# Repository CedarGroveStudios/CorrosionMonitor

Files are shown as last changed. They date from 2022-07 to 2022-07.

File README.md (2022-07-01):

# Corrosion_Monitor
 A CircuitPython and IoT version of the classic Workshop Corrosion Detector

Uses __CedarGroveStudios/Unit_Converter__ custom CircuitPython library.

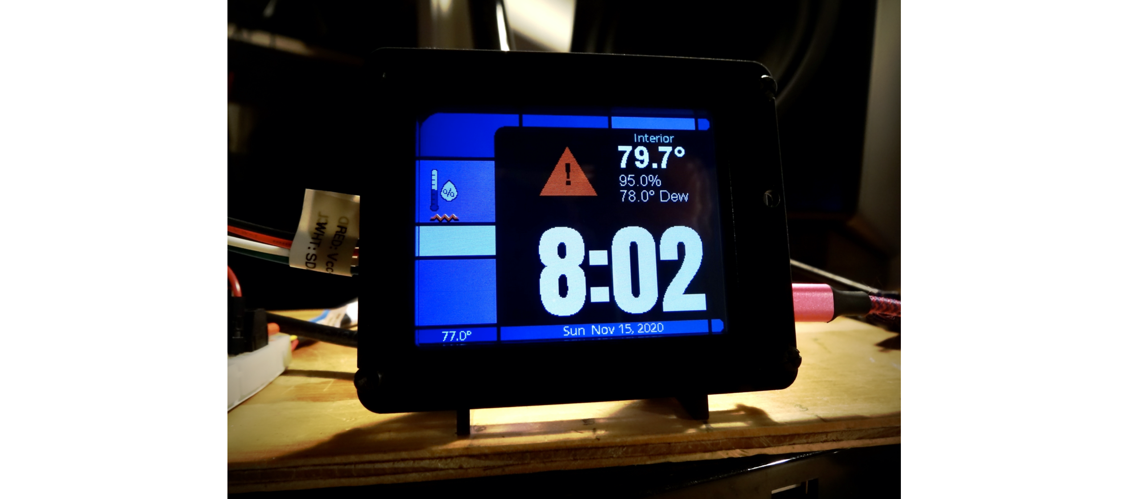
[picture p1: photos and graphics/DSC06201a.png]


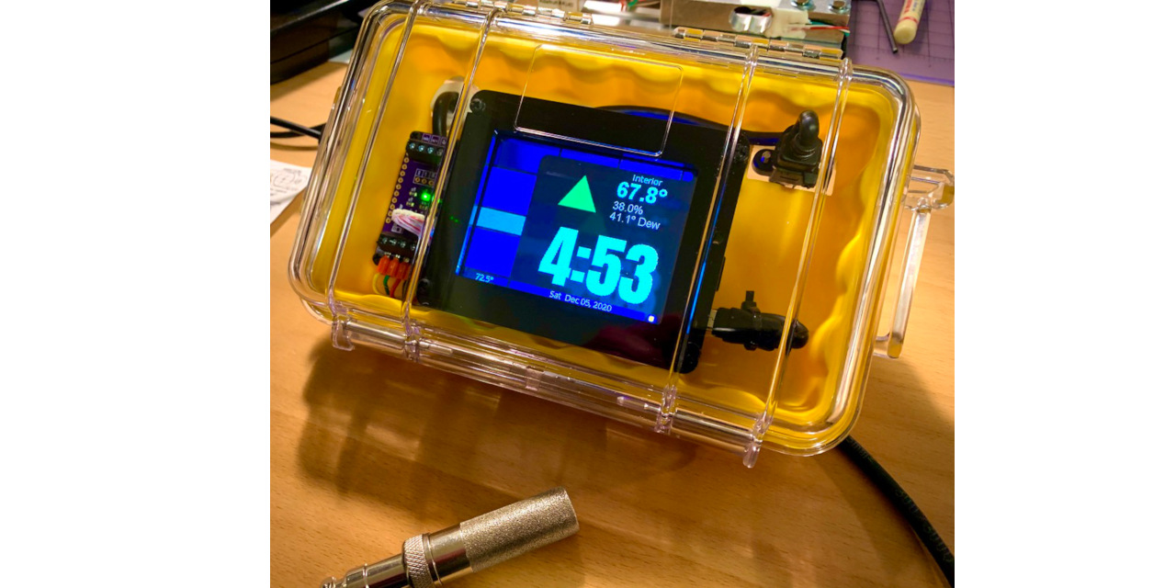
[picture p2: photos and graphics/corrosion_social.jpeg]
Corrosion_Monitor


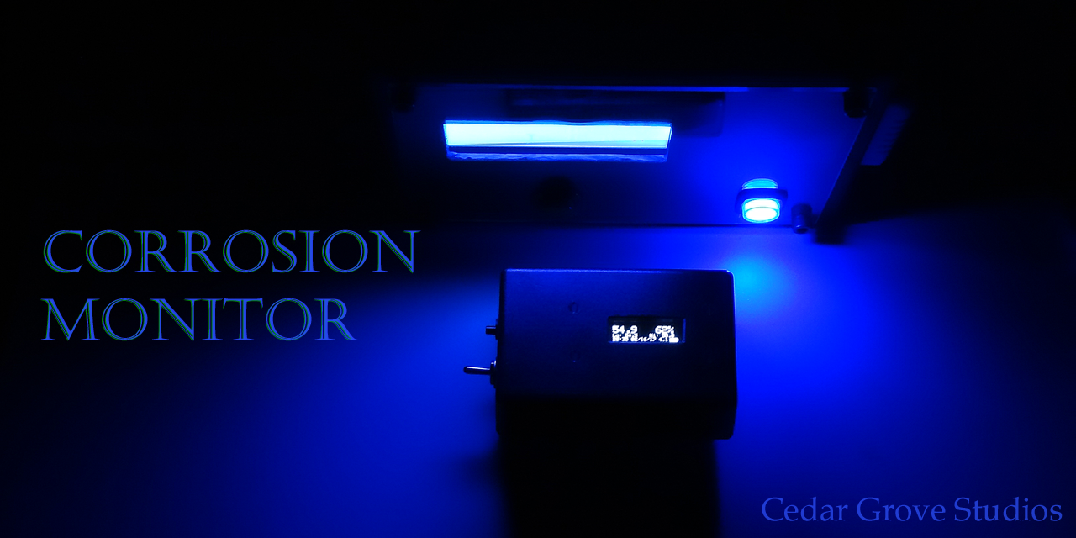
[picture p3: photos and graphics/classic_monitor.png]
Classic_Monitor


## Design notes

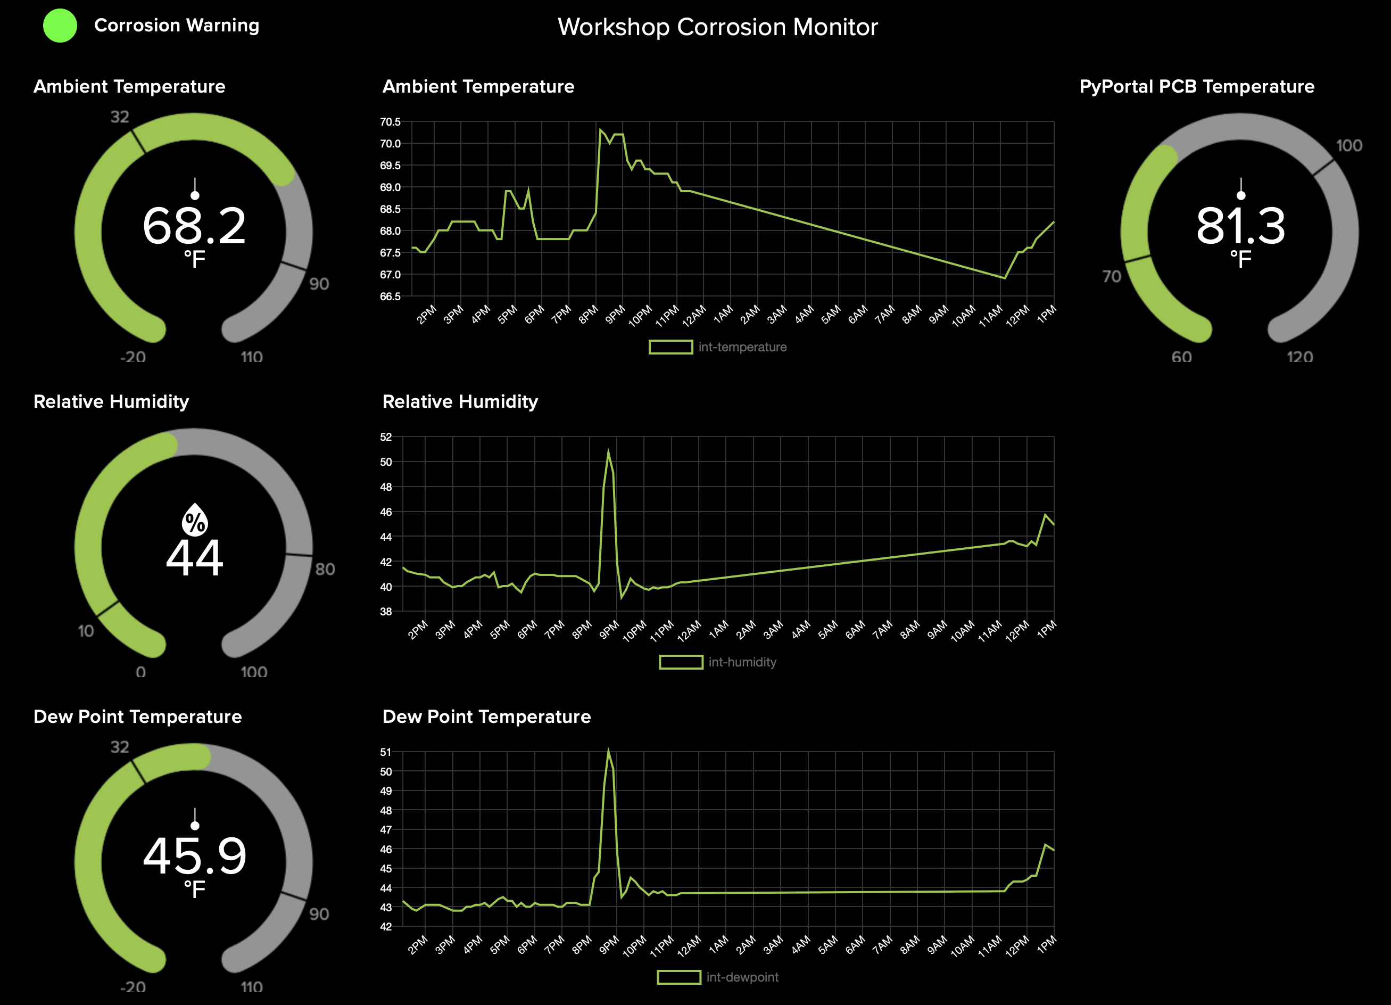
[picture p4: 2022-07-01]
photos and graphics/Screen Shot 2020-11-15 at 1.06.47 PM.png

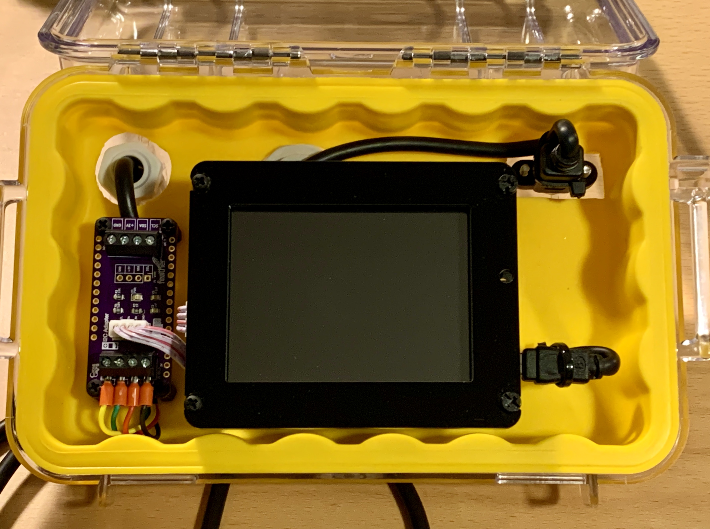
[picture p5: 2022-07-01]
photos and graphics/0E669820-88BB-440B-91F6-CADB1FE80EF4_1_201_a.jpeg

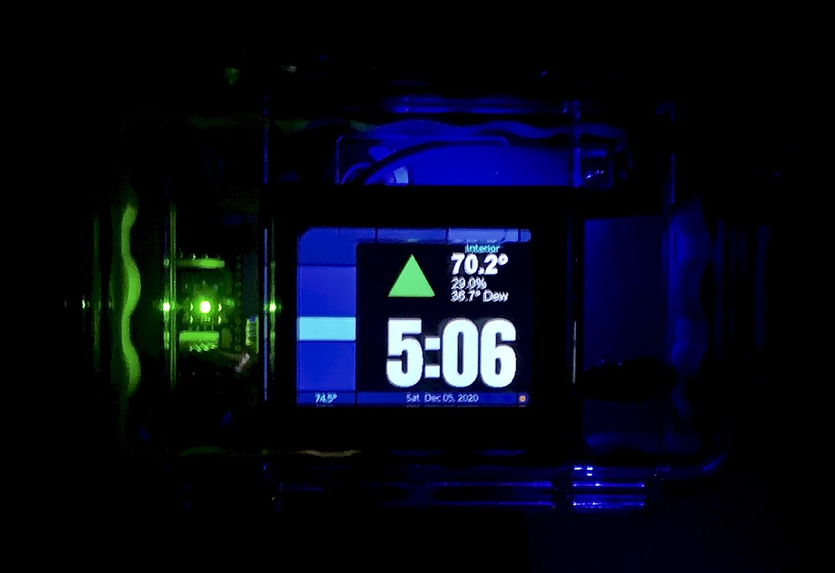
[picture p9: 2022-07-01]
photos and graphics/D59A51D9-286E-4AAB-B2BA-2F82D71A623C_1_105_c.jpeg

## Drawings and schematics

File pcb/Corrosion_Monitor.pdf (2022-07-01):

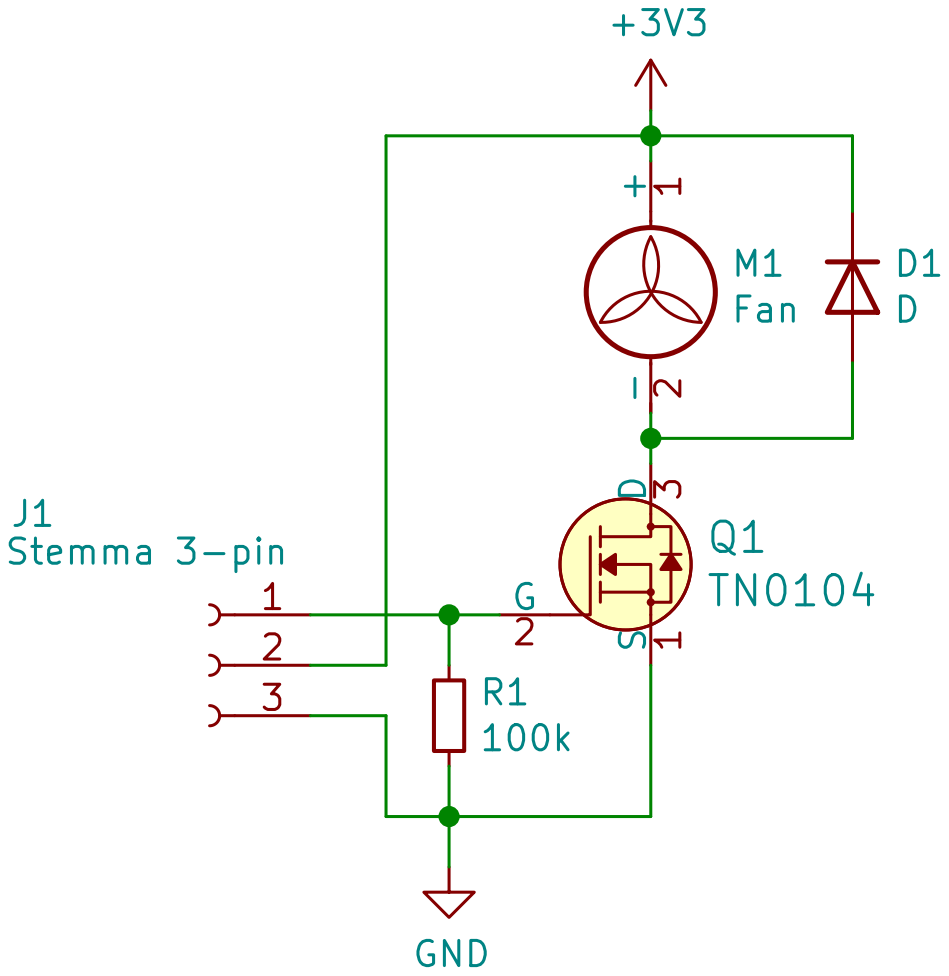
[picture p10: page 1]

File: Corrosion_Monitor.sch Sheet: / Cedar Grove Studios

Id: 1/1 Title: Corrosion_Monitorf Fan Controller

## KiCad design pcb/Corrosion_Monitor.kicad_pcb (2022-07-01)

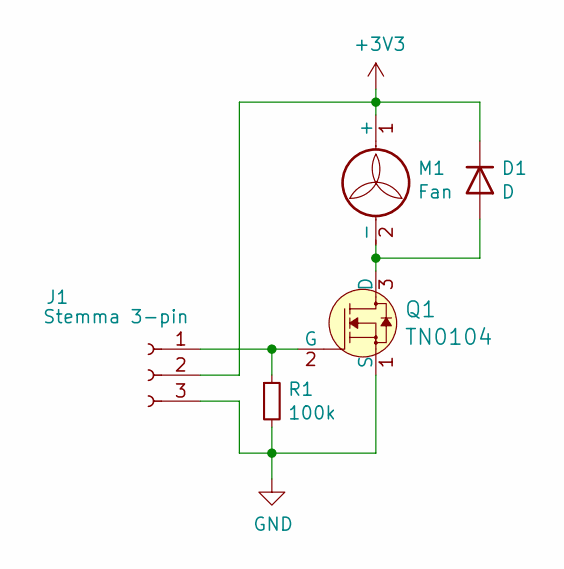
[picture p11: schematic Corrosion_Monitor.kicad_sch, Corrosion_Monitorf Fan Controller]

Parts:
D1: D; D_T-1_P2.54mm_Vertical_KathodeUp
J1: Stemma 3-pin; PinHeader_1x03_P2.54mm_Vertical
M1: Fan; PinHeader_1x02_P2.54mm_Vertical
Q1: TN0104; TO-92S; MPN 2N7000; Digi-Key_PN 2N7000FS-ND
R1: 100k; R_Axial_DIN0204_L3.6mm_D1.6mm_P2.54mm_Vertical

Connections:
+3V3: D1.1 (K), J1.2, M1.1 (+)
GND: J1.3, Q1.1 (S), R1.2
unnamed: D1.2 (A), M1.2 (-), Q1.3 (D)
unnamed: J1.1, Q1.2 (G), R1.1

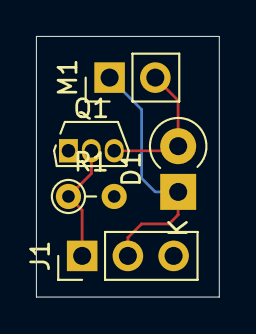
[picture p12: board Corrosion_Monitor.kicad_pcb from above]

Board: 2 copper layers, 10.2 x 14.5 mm, 5 parts (0 on the bottom side), 4 nets.

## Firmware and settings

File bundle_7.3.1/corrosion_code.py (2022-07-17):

# Workshop Corrosion Monitor
# Copyright 2018 to 2022 by JG for Cedar Grove Maker Studios
#
# corrosion_code.py 2022-07-17 v4.0717

import time
import board
import supervisor
from digitalio import DigitalInOut, Direction
from simpleio import map_range
from corrosion_display import CorrosionDisplay
from corrosion_sensors import CorrosionTempHumid, CorrosionTemp
from cedargrove_shadow_detector import ShadowDetector

print("running corrosion_code.py")

# Reduce status neopixel brightness to help keep things cool on error exit
# TODO: reduce TFT backlight brightness upon exit
supervisor.set_rgb_status_brightness(16)

# Force a restart upon error exit to keep things alive when the eventual
#   internet error happens
supervisor.set_next_code_file(filename="code.py", reload_on_error=True)

# fmt: off
# Adafruit IO Feed Names
SHOP_TEMP     = "shop.int-temperature"      # workshop temperature   (F)
SHOP_HUMID    = "shop.int-humidity"         # workshop humidity      (%)
SHOP_DP       = "shop.int-dewpoint"         # workshop dew point     (F)
SHOP_CORR     = "shop.int-corrosion-index"  # workshop corrosion indicator (0, 1, 2)
SHOP_PCB_TEMP = "shop.int-pcb-temperature"  # workshop device PCB temperature (F)

# Sensor and cluster sending delays
AIO_CLUSTER_DELAY  = 10  # minutes
AIO_CLUSTER_OFFSET =  5  # minutes
AIO_SENSOR_DELAY   =  2  # seconds
DUAL_SENSOR_DELAY  =  3  # seconds

# Cooling fan controls
FAN_ON_DISP_BRIGHTNESS =  0  # Display brightness when fan is running
FAN_ON_TRESHOLD_F      = 80  # Degrees Farenheit

# Gesture controls
GESTURE_DURATION = 10            # Backlight "on" duration after gesture (seconds)
GESTURE_DETECT_THRESHOLD = 0.90  # Detection threshold compared to ambient light

# Instantiate Corrosion Monitor classes
sensor  = CorrosionTempHumid(sensor="SHT31D")
pcb     = CorrosionTemp()
disp    = CorrosionDisplay(brightness=0.75)
gesture = ShadowDetector(pin=board.LIGHT, threshold=GESTURE_DETECT_THRESHOLD)

fan           = DigitalInOut(board.D4)  # D4 Stemma 3-pin connector
fan.direction = Direction.OUTPUT
fan.value     = False  # Initialize with fan off
# fmt: on

if disp.sd_card:
    print("SD card present")
else:
    print("NO SD card")

# fmt: off
while_loop_startup_init   = True   # Forces first pass through loop sections
previous_sensor_heater_on = False  # The historical sensor heater state
backlight_timer           = None   # Used for timing the backlight
backlight_on              = False  # The backlight state
clock_tick                = False  # The clock tick indicator state

aio_feed_write = True  # Enable feeds to AIO
sd_card_write  = True  # Enable sd card logging
# fmt: on

while True:
    now = time.localtime()
    format_str = "%04d-%02d-%02d, %02d:%02d:%02d"
    time_str = format_str % (now[0], now[1], now[2], now[3], now[4], now[5])

    disp.clock_tick = not disp.clock_tick  # Change the on-screen tick indicator

    if not backlight_on:
        # Check for gesture
        if gesture.detect():
            print(f"GESTURE DETECTED {time_str:16s}")
            backlight_timer = time.monotonic()
            backlight_on = True

    if backlight_on:
        # Set display brightness to maximum regardless of cooling fan state
        disp.brightness = 1.0
        # After GESTURE_DURATION seconds, dim the backlight
        if (time.monotonic() - backlight_timer) > GESTURE_DURATION:
            print(f"GESTURE TIMEOUT  {time_str:16s}")
            backlight_on = False
            print("Recalibrate light sensor background level")
            gesture.refresh_background()  # Update light sensor ambient level value
    else:
        # Set the idle backlight level when not responding to a gesture
        if fan.value:
            # Drop the brightness level dramatically until things cool down
            disp.brightness = FAN_ON_DISP_BRIGHTNESS
        else:
            # Set the display to a slightly dimmed level based on ambient level
            disp.brightness = map_range(gesture.background / 65535, 0.010, 0.750, 0.010, 0.5)

    # Do something every minute or when first starting the while loop
    if now.tm_sec == 0 or while_loop_startup_init:
        disp.show()  # Update clock display

        # Acquire and condition sensor data
        disp.sensor_icon = True
        disp.clock_tick = False
        sensor.read()  # Read temperature, humidity, dew_point, and corrosion_index
        temp_c, temp_f = sensor.temperature  # Get temperature values
        humid = sensor.humidity  # Get humidity value
        dew_pt_c, dew_pt_f = sensor.dew_point  # Get dew point values
        corrosion_index = sensor.corrosion_index  # Get corrosion index value

        pcb.read()  # Refresh the PCB temperature sensor
        pcb_c, pcb_f = pcb.temperature

        if pcb_f > FAN_ON_TRESHOLD_F:  # turn on cooling fan if needed
            fan.value = True
        else:
            fan.value = False

        # Send sensor values to the display
        disp.temperature = temp_c
        disp.humidity = humid
        disp.corrosion_status = corrosion_index
        disp.pcb_temperature = pcb_c

        # Display changed sensor heater status once
        if sensor.heater_on != previous_sensor_heater_on:
            if sensor.heater_on:
                disp.alert("Sensor heater: ON")
            else:
                disp.alert("Sensor heater: OFF")
        previous_sensor_heater_on = sensor.heater_on

        # Print temperature values to REPL
        print(
            "Fahrenheit: %16s, %3.1f, %3.1f, %3.1f"
            % (time_str, temp_f, humid, dew_pt_f)
        )
        print(
            "Celsius:    %16s, %3.1f, %3.1f, %3.1f"
            % (time_str, temp_c, humid, dew_pt_c)
        )

        disp.show(refresh=while_loop_startup_init)  # Enable the display
        while_loop_startup_init = False  # Reset the while loop startup flag

    # Do something every AIO_CLUSTER_DELAY starting at AIO_CLUSTER_OFFSET
    #   minutes past the hour
    if now.tm_min % AIO_CLUSTER_DELAY == AIO_CLUSTER_OFFSET and now.tm_sec < 10:
        # Send sensor data to the SD card and AIO
        if sd_card_write:
            sd_data_record = "%16s, %3.1f, %3.1f, %3.1f" % (
                time_str,
                temp_f,
                humid,
                dew_pt_f,
            )
            print("SD: " + sd_data_record)
            if disp.sd_card:
                disp.sd_icon = True
                log_file = open("/sd/logfile.csv", "a")
                log_file.write(sd_data_record)
                log_file.close()
                time.sleep(1)
                disp.sd_icon = False
            else:
                disp.alert("-- NO SD CARD")

        # Send sensor data to Adafruit IO
        if aio_feed_write:
            disp.show()  # Update the display
            # Send temperature to AIO feed
            if temp_f != None:
                disp._temperature.color = disp.BLUE
                disp.network_icon = True
                disp.pyportal.push_to_io(SHOP_TEMP, temp_f)
                disp.network_icon = False
                time.sleep(AIO_SENSOR_DELAY)
            disp._temperature.color = disp.WHITE

            disp.show()  # Update the display
            # Send humidity to AIO feed
            if humid != None:
                disp._humidity.color = disp.BLUE
                disp.network_icon = True
                disp.pyportal.push_to_io(SHOP_HUMID, humid)
                disp.network_icon = False
                time.sleep(AIO_SENSOR_DELAY)
            disp._humidity.color = disp.WHITE

            disp.show()  # Update the display
            # Send dew point temperature to AIO feed
            if dew_pt_f != None:
                disp._dew_point.color = disp.BLUE
                disp.network_icon = True
                disp.pyportal.push_to_io(SHOP_DP, dew_pt_f)
                disp.network_icon = False
                time.sleep(AIO_SENSOR_DELAY)
            disp._dew_point.color = disp.WHITE

            disp.show()  # Update the display
            # Send PyPortal PCB temperature to AIO feed
            if pcb_f != None:
                disp._pcb_temp.color = disp.BLUE
                disp.network_icon = True
                disp.pyportal.push_to_io(SHOP_PCB_TEMP, pcb_f)
                disp.network_icon = False
                time.sleep(AIO_SENSOR_DELAY)
            disp._pcb_temp.color = disp.CYAN

            disp.show()  # Update the display
            # Send corrosion index value to AIO feed
            if not None in (temp_f, dew_pt_f):
                disp._status_icon.fill = disp.BLUE
                disp._status.color = None
                disp.network_icon = True
                disp.pyportal.push_to_io(SHOP_CORR, corrosion_index)
                disp.network_icon = False
                disp.corrosion_status = corrosion_index  # refresh status
                time.sleep(AIO_SENSOR_DELAY)

            disp.show()  # Update the display

            try:
                # Update the local time from AIO time service
                disp.network_icon = True
                disp.clock_icon = True
                disp.clock_tick = False
                disp.pyportal.get_local_time()
                disp.clock_icon = False
                disp.network_icon = False
                now = time.localtime()
                time_str = format_str % (now[0], now[1], now[2], now[3], now[4], now[5])
                print("Time updated from AIO:", time_str)
            except (ValueError, RuntimeError) as e:
                disp.alert("-- Get time error -" + str(e))

        disp.show()  # Update the display
        disp.alert()  # Clear error notifications

    # Wait one second before looping (blocking)
    prev_sec = now.tm_sec
    while now.tm_sec == prev_sec:
        now = time.localtime()

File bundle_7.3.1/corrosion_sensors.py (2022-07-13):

# Workstation Corrosion Monitor
# Copyright 2018, 2019, 2020, 2021, 2022 by JG for Cedar Grove Maker Studios
#
# corrosion_sensors.py  2022-07-08 v3.0708

import time
import board
from analogio import AnalogIn

# Temperature Converter Helpers
from cedargrove_unit_converter.temperature import (
    celsius_to_fahrenheit,
    heat_index,
    dew_point,
)


class CorrosionTemp:
    """A sensor class for the PyPortal's integral temperature sensor."""

    def __init__(self, sensor="ADT7410", temp_delay=0.5):
        import adafruit_adt7410  # Integral I2C temperature sensor

        self._corrosion_sensor = adafruit_adt7410.ADT7410(board.I2C())
        self._corrosion_sensor.reset = True  # Set the sensor to a known state
        self._corrosion_sensor.high_resolution = True

        self._temp_delay = temp_delay
        self._temp_c = None
        self._temp_f = None

    @property
    def temperature(self):
        return self._temp_c, self._temp_f

    def read(self):
        """Update the temperature current value"""
        time.sleep(self._temp_delay)  # Wait to read temperature value
        self._temp_c = round(self._corrosion_sensor.temperature, 1)  # Celsius
        self._temp_f = round(celsius_to_fahrenheit(self._temp_c), 1)  # Fahrenheit
        return


class CorrosionLight:
    """A sensor class for the PyPortal's integral light sensor."""

    def __init__(self):
        """Instantiate the light sensor and measure the ambient light level."""
        self._sensor = AnalogIn(board.LIGHT)
        self.ambient_calibrate()

    @property
    def raw(self):
        """Acquire the current and ambient raw light sensor value."""
        self._read_sensor_value()
        return self._raw, self._ambient

    @property
    def normalized(self):
        """Acquire the current and ambient normalized light sensor value."""
        self._read_sensor_value()
        return self._raw / 65535, self._ambient / 65535

    @property
    def lux(self):
        """Acquire the current and ambient lux light sensor value. Full-scale
        raw value (65535) is approximately 1100 Lux."""
        self._read_sensor_value()
        return self._raw / 65535 * 1100, self._ambient / 65535 * 1100

    def _read_sensor_value(self):
        """Read and average sensor values. Adjust the ambient baseline
        with the new reading."""
        self._raw = 0
        for i in range(2000):
            self._raw = self._raw + self._sensor.value
        self._raw = self._raw / 2000
        self._ambient = (0.99 * self._ambient) + (0.01 * self._raw)

    def ambient_calibrate(self):
        """Establish an ambient light level."""
        self._ambient = 0
        for i in range(2000):
            self._ambient = self._ambient + self._sensor.value
        self._ambient = self._ambient / 2000


class CorrosionTempHumid:
    """A sensor class for the SHT31D-based indoor/outdoor and the AM2320-based
    indoor temperature and humidity sensors."""

    def __init__(self, sensor="SHT31D", temp_delay=3, humid_delay=4, debug=False):
        if sensor == "SHT31D":
            import adafruit_sht31d  # I2C temperature/humidity sensor; indoor/outdoor

            self._corrosion_sensor = adafruit_sht31d.SHT31D(board.I2C())
        if sensor == "AM2320":
            import adafruit_am2320  # I2C temperature/humidity sensor; indoor

            self._corrosion_sensor = adafruit_am2320.AM2320(board.I2C())

        self._corrosion_sensor.heater = False  # turn heater OFF
        self._heater_on = False
        self._temp_delay = temp_delay  # Temperature measurement delay (sec)
        self._humid_delay = humid_delay  # Humidity measurement delay (sec)
        self._temp_c = None
        self._temp_f = None
        self._dew_c = None
        self._dew_f = None
        self._humid_pct = None
        self._corrosion_index = 0  # 0:Normal, 1:Warning, 2:ALERT

        self._debug = debug
        if self._debug:
            print("*Init:\n", self.__class__)
            print("*Init:\n", self.__dict__)

    @property
    def temperature(self):
        return self._temp_c, self._temp_f

    @property
    def dew_point(self):
        return self._dew_c, self._dew_f

    @property
    def humidity(self):
        return self._humid_pct

    @property
    def corrosion_index(self):
        return self._corrosion_index

    @property
    def heater_on(self):
        return self._heater_on

    @heater_on.setter
    def heater_on(self, heater=False):
        self._heater_on = heater
        if self._heater_on:
            self._corrosion_sensor.heater = True  # Turn sensor heater ON
        else:
            self._corrosion_sensor.heater = False  # Turn sensor heater OFF
        return

    def read(self):
        """Update the temperature and humidity with current values,
        calculate dew point and corrosion index"""
        time.sleep(self._temp_delay)  # Wait to read temperature value
        self._temp_c = self._corrosion_sensor.temperature
        if self._temp_c != None:
            self._temp_c = min(max(self._temp_c, -40), 125)  # constrain value
            self._temp_c = round(self._temp_c, 1)  # Celsius
            self._temp_f = round(celsius_to_fahrenheit(self._temp_c), 1)  # Fahrenheit
        else:
            self._temp_f = None
        time.sleep(self._humid_delay)  # Wait to read humidity value
        self._humid_pct = self._corrosion_sensor.relative_humidity
        if self._humid_pct != None:
            self._humid_pct = min(max(self._humid_pct, 0), 100)  # constrain value
            self._humid_pct = round(self._corrosion_sensor.relative_humidity, 1)

        # Calculate dew point values
        if None in (self._temp_c, self._humid_pct):
            self._dew_c = None
            self._dew_f = None
        else:
            self._dew_c = dew_point(self._temp_c, self._humid_pct)
            self._dew_f = round(celsius_to_fahrenheit(self._dew_c), 1)

        # calculate corrosion index value; keep former value if temp or dewpoint = None
        if None in (self._temp_c, self._dew_c):
            return
        else:
            if (self._temp_c <= self._dew_c + 2) or self._humid_pct >= 80:
                self._corrosion_index = 2  # CORROSION ALERT
                self._corrosion_sensor.heater = True  # turn heater ON
                self._heater_on = True
            elif self._temp_c <= self._dew_c + 5:
                self._corrosion_index = 1  # CORROSION WARNING
                self._corrosion_sensor.heater = False  # turn heater OFF
                self._heater_on = False
            else:
                self._corrosion_index = 0  # NORMAL
                self._corrosion_sensor.heater = False  # turn heater OFF
                self._heater_on = False
        return

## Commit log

2022-07-01 initial repo load
    [Corrosion_Monitor.kicad_pcb, Corrosion_Monitor.kicad_sch, Corrosion_Monitor.sch]
2022-07-07 increase light sensor averaging to improve gesture detection range
2022-07-07 update gesture logic; recalibrate background light calibration after timeout and once per minute
2022-07-07 add clock tick to on-board neopixel
2022-07-08 improve ambient light detection; upgrade to CircuitPython 7.3.1
2022-07-13 improve light sensor measurement stability for light flicker
    [corrosion_code.py, corrosion_sensors.py, pyportal_gesture_example.py]
